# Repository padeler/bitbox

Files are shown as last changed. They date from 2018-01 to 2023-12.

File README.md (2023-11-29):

# bitbox
RGB Led matrix for clock/weather/info/animations.

Bitbox is a RGB LED matrix controlled using an arduino board. It combines the functions of the [GameFrame](https://ledseq.com/product/game-frame) by LEDSEQ and the [RibbaPi](https://github.com/stahlfabrik/RibbaPi). 

Bitbox can work as a standalone device displaying data/time or controlled over USB to display images send by the host.

This repository contains arduino code and build notes for the bitbox display.

For the s/w on the PC side check the [Pybitbox](https://github.com/padeler/Pybitbox) repository.  

## 3rd party arduino libraries 

- WS2812 control: [FastLED](https://github.com/FastLED/FastLED)
- [Time](https://www.pjrc.com/teensy/td_libs_Time.html)
- [DS1307RTC](https://github.com/PaulStoffregen/DS1307RTC) 

Testing:
- [SD](https://www.arduino.cc/reference/en/libraries/sd/)
- 

## Useful links

- [Power Topology](https://learn.adafruit.com/1500-neopixel-led-curtain-with-raspberry-pi-fadecandy/power-topology)

## Making-of bitbox 

The 16x16 matrix is made of four 8x8 panels of WS2812 RGB LEDs I got from [hobbyking](https://hobbyking.com/en_us/2812-8-8-64-bit-full-color-5050-rgb-led-module.html).
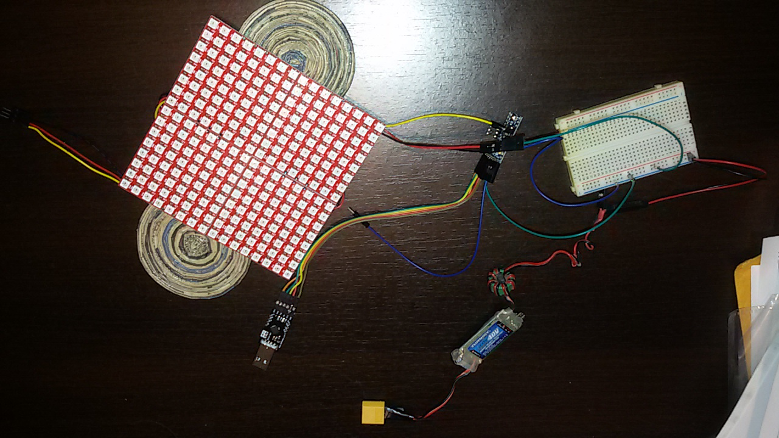
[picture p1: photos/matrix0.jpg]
matrix0

Since I will most probably make changes in the future, I used connectors wherever possible.
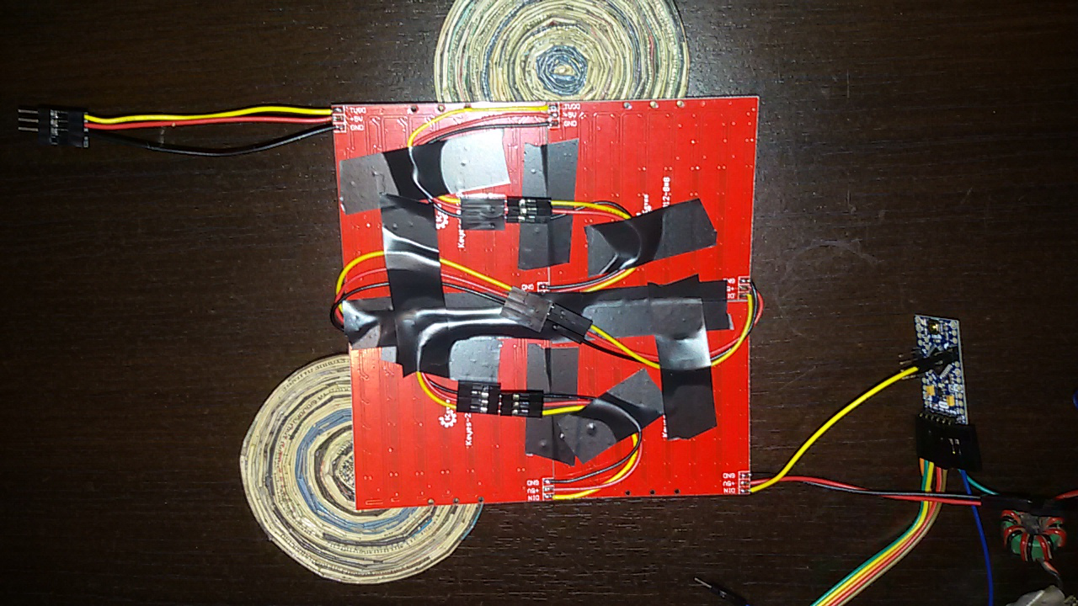
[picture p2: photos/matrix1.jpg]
matrix1

Testing the leds to make sure all are working ok.
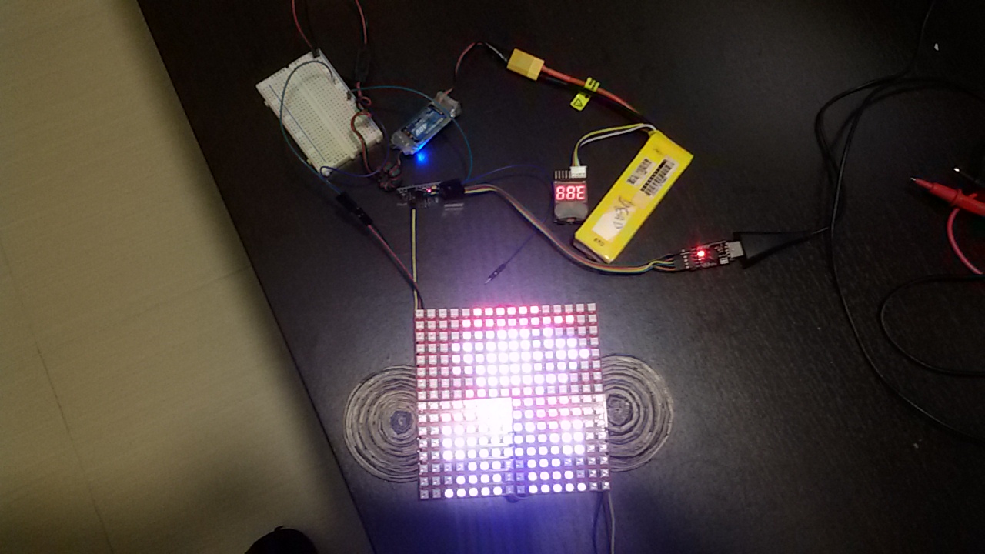
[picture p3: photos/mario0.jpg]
screen test without diffuser

In order to get a nice "pixel" effect a diffuser is needed. Here the diffuser is a piece of A4 paper.
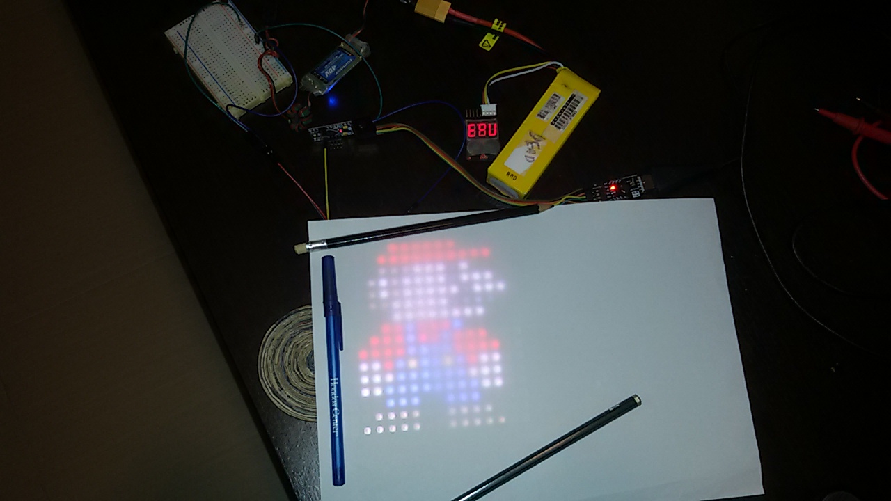
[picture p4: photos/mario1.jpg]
screen test with paper diffuser

For the final assembly, a 5mm piece of tinted plexiglas and a thinner piece of paper is used. 
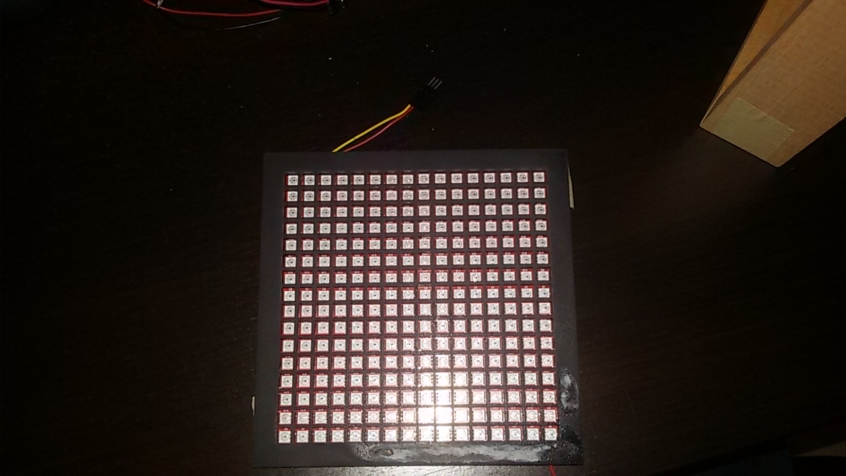
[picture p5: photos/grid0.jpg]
Grid on led matrix

A [3D printed](/model/diffuser_grid.scad) grid goes between the diffuser and the LED panel. 
This helps create a nice "square" pixel effect.
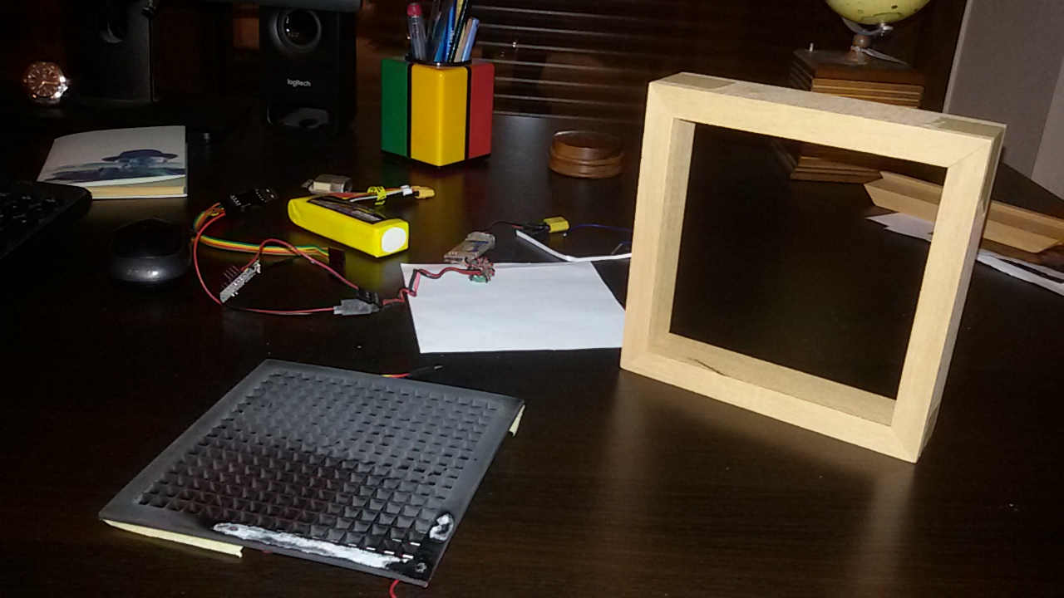
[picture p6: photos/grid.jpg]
diffuser grid and wooden frame

Putting everything together. The wooden frame before painting.
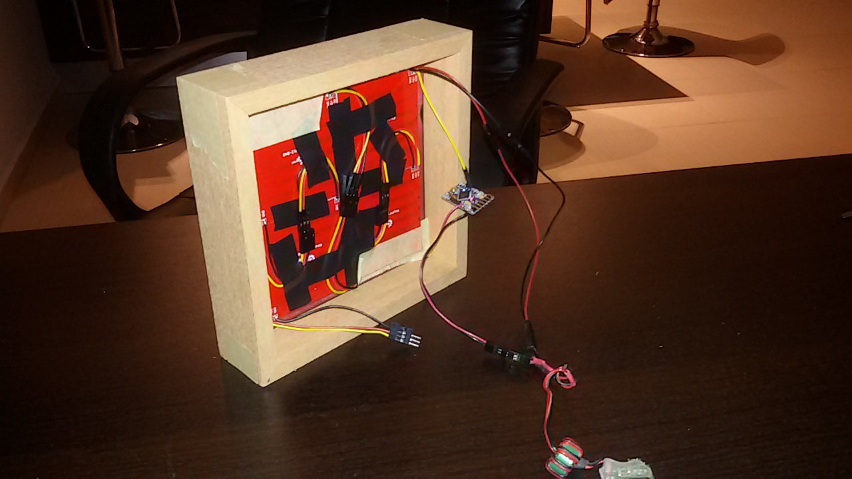
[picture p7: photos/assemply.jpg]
electronics assembly in the wooden frame

Testing the clock function. Here the just a paper diffuser is used.
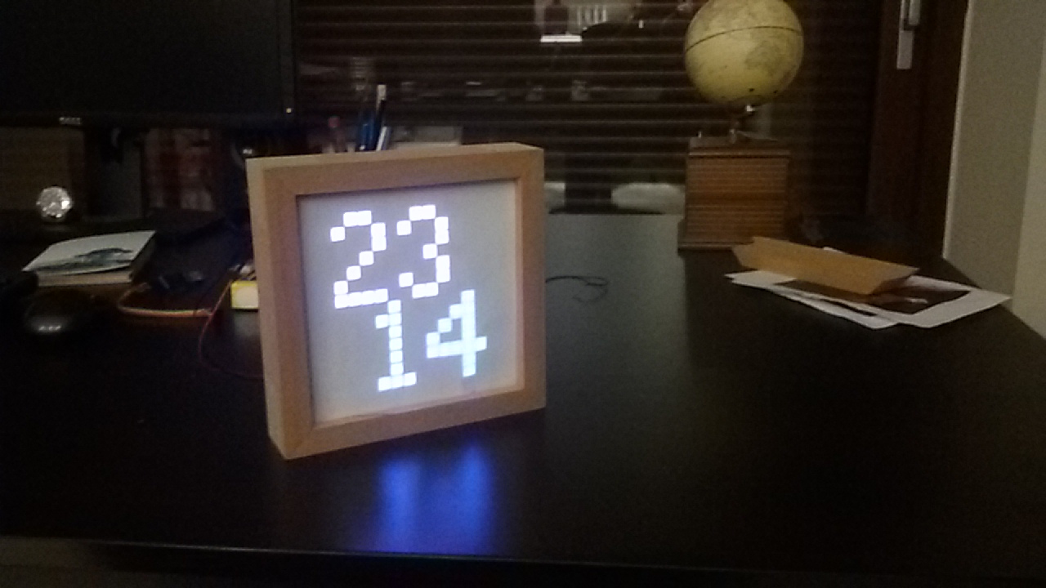
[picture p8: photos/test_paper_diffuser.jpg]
test with frame and paper diffuser

More testing with the tinted plexiglas diffuser. The clock set to the "pong" clock-face.
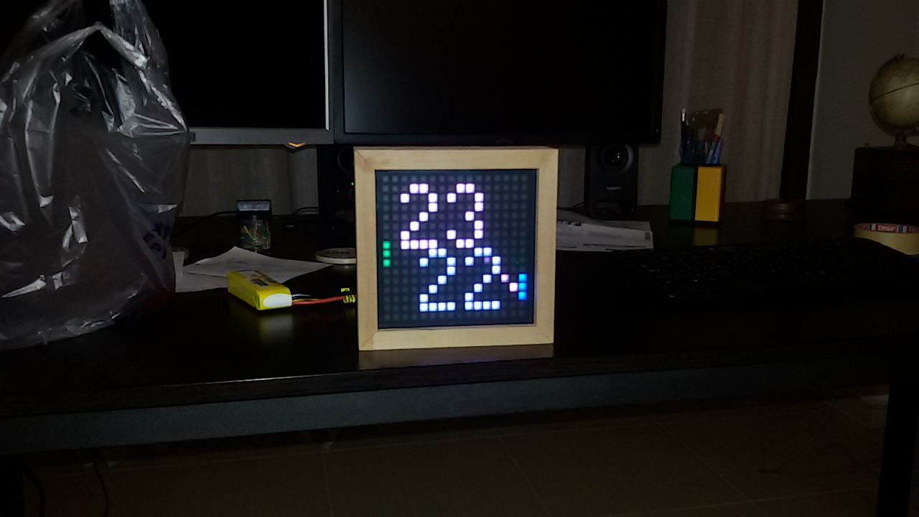
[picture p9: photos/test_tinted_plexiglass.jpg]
test with Plexiglas diffuser

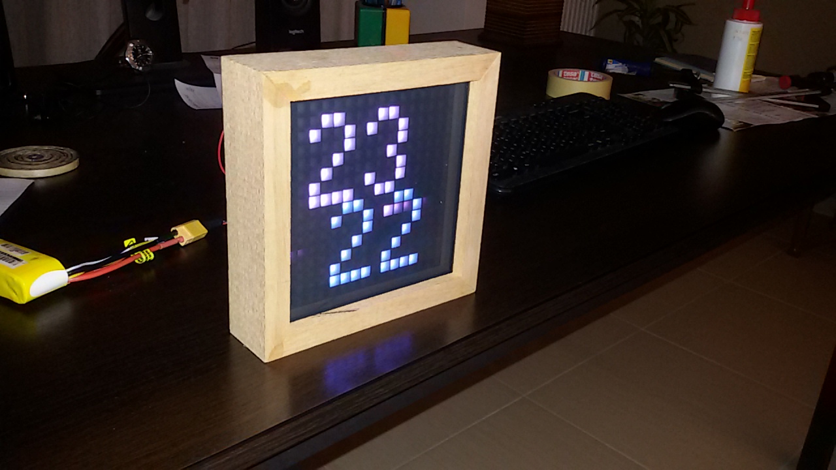
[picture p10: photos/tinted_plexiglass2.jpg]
test tinted Plexiglas closeup

A 3mm piece of white plexiglas is used for the back cover. 
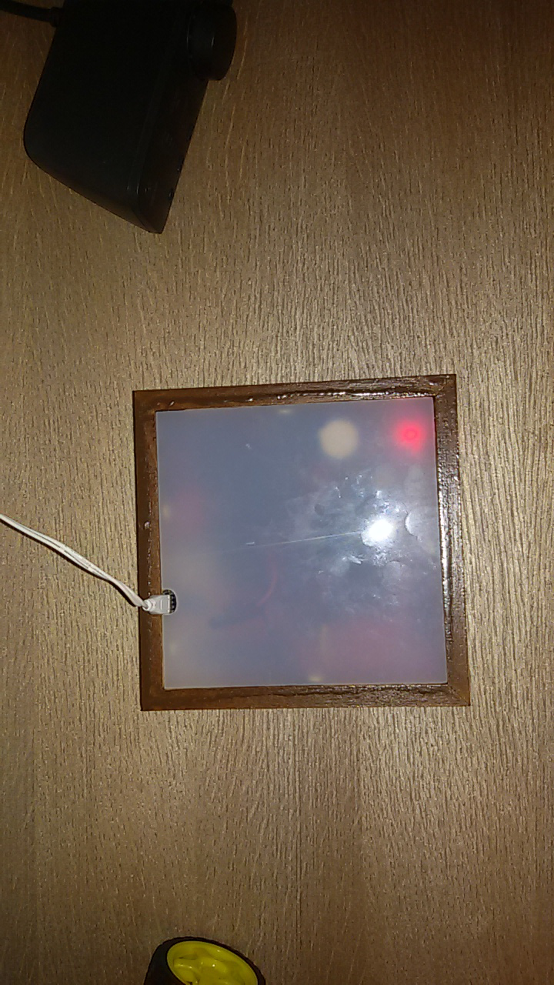
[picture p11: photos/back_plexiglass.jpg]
back side plexiglas

The USB port is used for powering the frame and electronics and for serial connection with the arduino.
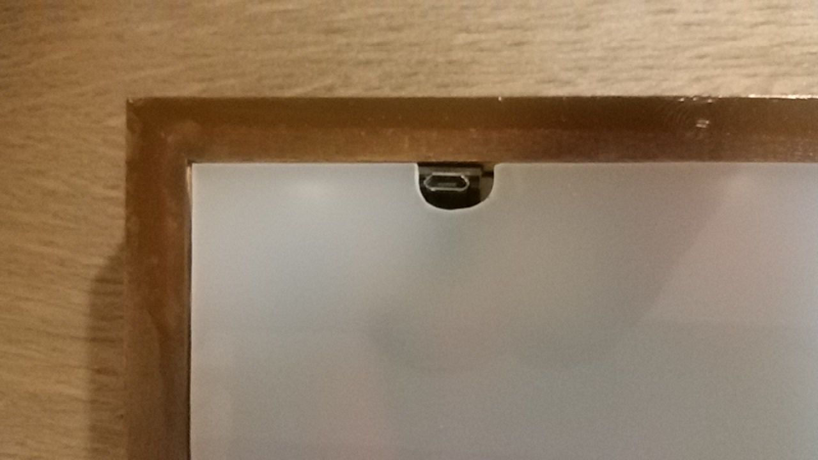
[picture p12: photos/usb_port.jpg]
USB port for power and serial comm

The final result: Bitbox in clock mode with the "break-out" clock-face.
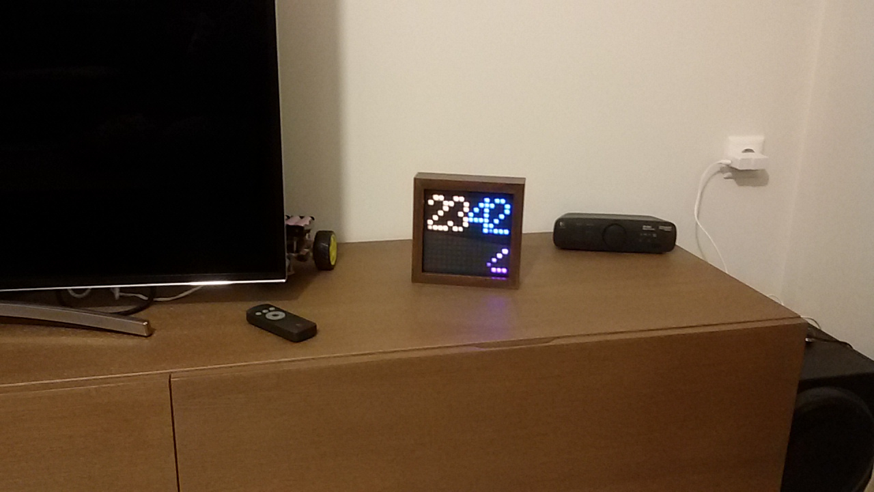
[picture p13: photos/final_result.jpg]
final result


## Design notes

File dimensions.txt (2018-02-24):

Screen (grid frame): 150x150mm
Screen (view-able area): 140x140mm

Patoura gia to grid 5mm apo kathe plevra

Wooden frame: 15mm (10mm border, 5mm patoura)
Depth: 50mm
Back: dont know

Total dims: 15*2 + 140 = 170mm

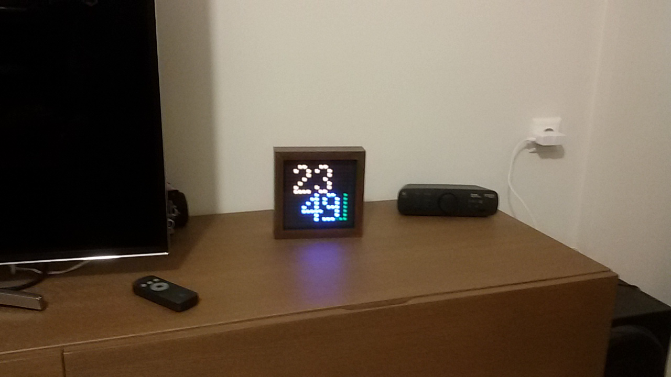
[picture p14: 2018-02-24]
photos/snake.jpg

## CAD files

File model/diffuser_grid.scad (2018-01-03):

rows = 8; 
total_length = 65+1;

rows = 8*2; 
total_length = 65*2 + 2;


thickness = 1.2; // max led-led distance 3.2mm
length = total_length - thickness ; 
height = 6; // can range from 5-10mm
side = length/rows;
lip = 1.2; // min lip is 1mm

frame = 9; // width of frame
frame_thickness = 3;

// Total size is 150 = frame*2 + total_length

module lines(trx, try) {
    translate([0,try,lip]) cube([length,thickness,height-lip]);
    translate([trx,0, 0]) cube([thickness,length,height]);
}

module base(){
    cube([length,thickness,height]);
    cube([thickness,length,height]);
    
    translate([0,side*(rows),0]) color("ForestGreen") cube([total_length,thickness,height]);
    translate([side*(rows),0,0]) color("ForestGreen") cube([thickness,total_length,height]);
    
    for(i= [0:rows-1]){
        lines(i*side, i*side);
    }
}

//base();
//rotate(a=[180,0,0]) translate([0,0,-height]) base();

module framed(){
    base();
    translate([-frame, -frame, height-frame_thickness]) cube([total_length + frame*2, frame, frame_thickness]);
    translate([-frame, total_length, height-frame_thickness]) cube([total_length + frame*2, frame, frame_thickness]);


    translate([-frame, -frame, height-frame_thickness]) cube([frame, total_length + frame*2, frame_thickness]);

    translate([total_length, -frame, height-frame_thickness]) cube([frame, total_length + frame*2, frame_thickness]);
}


//framed();
rotate(a=[180,0,0]) translate([frame,-total_length-frame,-height]) framed();

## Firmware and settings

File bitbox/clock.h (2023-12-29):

#pragma once

#include "display.h"
#include "transitions.h"

#define NIGHT_BRIGHTNESS 5
#define DAY_BRIGHTNESS 10

#define NIGHT_HOUR 23
#define DAY_HOUR 8

#define CLOCK_MODE_STARFIELD 0
#define CLOCK_MODE_SNAKE 1
#define CLOCK_MODE_PONG 2
#define CLOCK_MODE_BREAKOUT 3
#define CLOCK_MODE_MATRIX 4
#define CLOCK_MODE_FIRE 5
#define CLOCK_MODE_MARIO 6
#define CLOCK_MODE_PLAIN 7 // also max
#define CLOCK_MODE_RANDOM 128

#define DEFAULT_CLOCK_MODE CLOCK_MODE_RANDOM

#define DEFAULT_BG_CHANGE 180000 // millis

#define CLOCKFACE_MS_PER_FRAME 125 // redraw clock  at most this often


// Pong defines
#define PL 1
#define PR 4
#define PB 6

#define CLOCK_NUM_POINTS 8

struct Point
{
  Point(){};
  Point(int x, int y) : x(x), y(y){};
  int8_t x, y;
};


class ClockFace: public Animation
{
public:

  ClockFace(uint8_t mode): clock_mode(mode)
  {
    hh = -1;
    mm = -1;
    last_repaint = 0;
  }

  void draw_time(Display *dsp, const Point &h_pos, const Point &m_pos, const CRGB &h_color, const CRGB &m_color, bool clear_before_draw, bool compact, bool overlay, bool force_redraw);
  
  virtual ~ClockFace() throw() {}
  virtual bool update_clock_face(Display *dsp, bool force_redraw);

  bool update(Display *dsp, bool force_redraw)
  {
    // clear screen on first run
    if(last_repaint==0 || force_redraw) dsp->fillrect(0,0,16,16, CRGB::Black);

    if(millis()-last_repaint>CLOCKFACE_MS_PER_FRAME || force_redraw){
      update_clock_face(dsp, force_redraw);
      dsp->repaint();
      last_repaint = millis();
    }
    return false; // ClockFace animations never end (its a clock)
  }

  
  uint8_t clock_mode;
  int hh, mm;
  unsigned long last_repaint;
};

class Starfield: public ClockFace
{
public:
  #define NUM_STARS 10
  Starfield(): ClockFace(CLOCK_MODE_STARFIELD)
  {
    colorIndex = 0;
    delta_color = 1;
    vertical = false;

    for (int8_t i = 0; i < NUM_STARS; i++)
    {
      h_points[i].x = MATRIX_WIDTH / 2;
      h_points[i].y = MATRIX_HEIGHT / 2;
    }
  }
  
  bool update_clock_face(Display *dsp, bool force_redraw);

  int8_t delta_color;
  uint8_t colorIndex;
  bool vertical;


  Point h_points[NUM_STARS];
};

class Breakout: public ClockFace
{
public:
  Breakout(): ClockFace(CLOCK_MODE_BREAKOUT)
  {
    dx = dy = 1;
    ball.x=MATRIX_WIDTH/2;
    ball.y=MATRIX_HEIGHT-3;
    pad.x = MATRIX_WIDTH/2;
    pad.y = MATRIX_HEIGHT-1;
    ball_bg = CRGB::Black;
  }

  void update_breakout_pad();
  bool update_clock_face(Display *dsp, bool force_redraw);

  int8_t dx,dy;
  Point pad, ball;
  CRGB ball_bg;
};

class MultiClockFace : public ClockFace
{
public:
  MultiClockFace(uint8_t mode): ClockFace(mode)
  {

    snake_head = 0;
    colorIndex = 0;
    delta_color = 1;
    motion = 1;
    dx = 1;
    dy = 1;
    last_repaint = 0;

    for (int8_t i = 0; i < CLOCK_NUM_POINTS; i++)
    {
      h_points[i].x = MATRIX_WIDTH / 2;
      h_points[i].y = MATRIX_HEIGHT / 2;
    }
  }



  bool update_clock_face(Display *dsp, bool force_redraw)
  {
    switch (clock_mode & 0x0F)
    {
    case CLOCK_MODE_SNAKE:
      draw_snake(dsp, force_redraw);
      break;
    case CLOCK_MODE_PONG:
      draw_pong(dsp, force_redraw);
      break;
    case CLOCK_MODE_MARIO:
      draw_mario(dsp);
      break;
    case CLOCK_MODE_MATRIX:
      draw_matrix(dsp, force_redraw);
      break;
    case CLOCK_MODE_FIRE:
      draw_fire(dsp, force_redraw);
      break;
    default: // CLOCK_MODE_PLAIN
      draw_time(dsp, Point(2, 0), Point(5, 8), CRGB::White, CRGB::White, true, false, true, force_redraw);
      break;
    }
    return false;
  }


  void draw_matrix(Display *dsp, bool force_redraw);
  void draw_mario(Display *dsp);
  void draw_fire(Display *dsp, bool force_redraw);
  void draw_starfield(Display *dsp, bool force_redraw);
  void draw_snake(Display *dsp, bool force_redraw);
  void draw_pong(Display *dsp, bool force_redraw);
  void update_pong_pad(int8_t idx, int8_t xpos);

  void clear_points(Display *dsp)
  {
    for (int8_t i = 0; i < CLOCK_NUM_POINTS; i++)
    {
      dsp->set(h_points[i].x, h_points[i].y, CRGB::Black);
    }
  }

  void fade_points(Display *dsp, uint8_t amount)
  {
    for (int8_t i = 0; i < CLOCK_NUM_POINTS; i++)
    {
      dsp->get(h_points[i].x, h_points[i].y).nscale8(amount);
    }
  }

  int8_t delta_color;
  int8_t dx, dy;
  int8_t motion;
  uint8_t colorIndex;
  unsigned long anim_frame;

  uint8_t snake_head;
  Point h_points[CLOCK_NUM_POINTS];

};


/* ***************************************************************** */
/* ***************************  CLOCK  ***************************** */
/* ***************************************************************** */

class Clock
{

public:
  Clock()
  {
    last_bg_change = 0;
    current_face = NULL;
  }

  void update_clock_face(Display *dsp)
  {

    if(current_face!=NULL && millis() - last_bg_change<DEFAULT_BG_CHANGE) return; 
    
    uint8_t clock_mode;
    if(current_face!=NULL) clock_mode = current_face->clock_mode;
    else clock_mode = DEFAULT_CLOCK_MODE & 0xFF;
    
    if(hour() >= DAY_HOUR && hour() <= NIGHT_HOUR)
    {
      dsp->set_brightness(DAY_BRIGHTNESS);

      if(DEFAULT_CLOCK_MODE & CLOCK_MODE_RANDOM)
      {
        clock_mode = (clock_mode + (uint8_t)random(CLOCK_MODE_PLAIN - 1)) % CLOCK_MODE_PLAIN;
      }
    }
    else
    { // night time, use plain clock mode
      dsp->set_brightness(NIGHT_BRIGHTNESS);
      clock_mode = CLOCK_MODE_PLAIN;
    }

    last_bg_change = millis();

    if(current_face==NULL || current_face->clock_mode!=clock_mode)
    { // remove old clock face and add a new one. 
      // NOTE: no need to delete old clock face, the animation is deleted on pop.
      dsp->animation_delete(current_face); 
      current_face = create_face_animation(clock_mode);
      dsp->animation_push(current_face);

      if(random8(0,2)==0)
        dsp->animation_push(new Collapse()); // transition
      else
        dsp->animation_push(new Melt()); // transition

    }
  }

  ClockFace *create_face_animation(uint8_t clock_mode)
  {
    switch (clock_mode & 0x0F)
    {
      case CLOCK_MODE_BREAKOUT:
        return new Breakout();
      case CLOCK_MODE_STARFIELD:
        return new Starfield();
      default: // multi face clock anim  
        return new MultiClockFace(clock_mode);
    }
  }
  
  unsigned long last_bg_change;
  ClockFace *current_face;
};

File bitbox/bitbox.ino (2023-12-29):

#include <TimeLib.h>
#include <Wire.h>
#include <DS1307RTC.h>

// Including <SD.h> caused a crash on boot probably memory issue on the arduino
// Older versions used to work (circa 2019). Probably wont be an issue with stronger hardware.
// #include <SD.h>

#include <stdint.h>
#include <WString.h>

#include "display.h"
#include "utils.h"
#include "clock.h"
// #include "heart.h"

#include "transitions.h"

#include "message.h"

// #include "Adafruit_Sensor.h"
// #include "DHT.h"

#define DHTTYPE DHT22   // DHT 22  (AM2302), AM2321
#define DHTPIN 7

#define SS_PIN 4 // SD CARD SS PIN

#define TARGET_MS_PER_FRAME 30
#define DEFAULT_TIME 1514589221


/* ***************************************************************** */
/* ************************* MAIN SKETCH *************************** */
/* ***************************************************************** */

CommHandler *handler = NULL;

Display *dsp;
Clock *clk;


unsigned long last_repaint = 0;

// uint8_t heart_fr=0;

unsigned long last_upd=0;

// DHT dht(DHTPIN, DHTTYPE);

void setup() {
  pinMode(LED_BUILTIN, OUTPUT);
  // Serial.begin(115200);
  Serial.begin(9600);
  Serial.setTimeout(1000);
  randomSeed(analogRead(0));
  
  // TODO load config from EEPROM
  
  // Initialize thermometer/humidity lib
  // dht.begin();

  // initialize display
  dsp = new Display();
  
  // initialize clock
  clk = new Clock();

  // init communication handler
  if(Serial) handler = new CommHandler(dsp);
  else handler = NULL;
  
  setSyncProvider(RTC.get);
  if(timeStatus() != timeSet)
  {
    setTime(DEFAULT_TIME);
    Serial.println(F("Unable to sync with the RTC"));
  }
  else
  {
    Serial.println(F("RTC has set the system time"));
  }


  // Serial.print(F("Initializing SD card..."));
  // if (!SD.begin(SS_PIN)) {
  //   Serial.println(F("failed!"));
  //   return;
  // }
  // Serial.println(F("OK!"));

  // initialize first clock face
  clk->update_clock_face(dsp);
  // add a transition
  // dsp->animation_push(new Melt());  
  // push a text message animation
  Message *msg = new Message(F("bitbox"), 16,5,-1,0,false);
  dsp->animation_push(msg); 
}

void serialEvent()
{
  digitalWrite(LED_BUILTIN, HIGH);
  while(Serial.available()>0)
  {
    int val = Serial.read();
    if(val>=0 && handler)
    {
      handler->process(val);
    }
  }
  digitalWrite(LED_BUILTIN, LOW);
}



// For debugging
// bool blink=false;
// byte i=0,j=0;

void loop() {
  
  // CRGB colors[4] = { CRGB::Red, CRGB::Green, CRGB::Blue , CRGB::Black};
  // dsp->set(i%16, i/16,colors[j%4]);
  // dsp->repaint();
  // i++;
  // if(i==0) j++;
  
  if(handler && handler->isReceiving()){
    handler->check_timeout();
  }
  else if(Serial.available()==0)
  { //only if serial IO is not pending


    // if(day()==28 && month()==4 && hour()>=8)
    // {
      // draw_heart();
    // }
    // else
    { 
    // update_temp();
      clk->update_clock_face(dsp);
    } 

    if(millis()-last_repaint>TARGET_MS_PER_FRAME){
      dsp->flush_buffer();
      last_repaint = millis();

      // // blink a led 
      // if(blink)
      // {
      //   digitalWrite(LED_BUILTIN, HIGH);
      // }
      // else{
      //   digitalWrite(LED_BUILTIN, LOW);      
      // }
      // blink = !blink;
    }
  }

}

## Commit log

2018-01-03 Increase frame width.
    [diffuser_grid.scad]
2018-01-31 Adds mario clock face. Fixes some minor bugs
    [bitbox.ino, clock.h]
2018-02-04 bug fix in breakout
    [clock.h]
2018-04-22 Added night mode. Some code clean-up and minor fixes
    [bitbox.ino, clock.h, display.h]
2018-04-23 Bugfix in clock initialization
    [bitbox.ino, clock.h]
2018-04-28 Animation class and basic wiring
2018-04-29 Animations framework ready. Added example message animation
2018-06-28 DHT sensor functions
2023-12-28 Removes unused SD.h which causes a memory issue.
    [bitbox.ino, display.h]
2023-12-29 Enable fire and mario faces, fix bug in breakout
    [bitbox.ino, clock.h, draw_bmp.cpp]
